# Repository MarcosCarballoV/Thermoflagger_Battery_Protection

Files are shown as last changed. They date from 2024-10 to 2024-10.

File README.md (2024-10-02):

# Thermoflagger Battery Protection Overheat




## Overview

This design monitors battery temperature to protect LiPo and Li-ion batteries from overheating. It disconnects the battery at 60°C and automatically reconnects at 50°C, ensuring safety during charging and discharging cycles while consuming just 2.6 µA in overheat protection mode.

The Toshiba Thermoflagger (model TCTH011AE) is essential for automatic battery disconnection and reconnection, as non-latch models are unsuitable for this purpose. Additionally, the design incorporates the BQ24075 battery charger IC, which features a dedicated pin for battery disconnection, further enhancing safety with real-time

<p align="center">
  Thermoflagger_Operating
  <br>
  <em>Thermoflagger - Automatic battery disconnection and reconnection </em>
</p>

## Thermoflagger

Toshiba’s Thermoflagger™ devices are designed for effective over-temperature monitoring and protection. These devices utilize a constant current source to detect temperature changes, ensuring high accuracy without the need for supply voltage stabilization.

### How the IC Operates
The Thermoflagger™ connects to a PTC thermistor via the PTCO pin. The built-in constant current source generates a low voltage across the PTC thermistor. As temperature increases, the resistance of the thermistor rises exponentially, causing a voltage increase at the PTCO pin. This voltage change is detected by the Thermoflagger™, which then generates a FLAG signal to the MCU for further actions. Multiple PTC thermistors can be connected in series for monitoring at various points within a system.

<p align="center">
  Thermoflagger_HowOperates
  <br>
  <em>How the Thermoflagger Operates</em>
</p>

### Features
- **High accuracy:** No supply voltage stabilization required.
- **Current source for temperature detection:** Efficient and reliable.

### Overheat Detection
The Thermoflagger™ provides a warning signal upon detecting a change in resistance in the PTC thermistor, indicating potential overheat conditions.

## BQ24075 Overview
The BQ24075 is part of the BQ2407x series of integrated Li-Ion linear chargers and system power path management devices, specifically designed for space-limited portable applications.

This device features **Battery Disconnect Function** with a SYSOFF input, ensuring that the battery can be disconnected safely when needed.

<p align="center">
  BQ24075_Circuit
  <br>
  <em>BQ24075 - Typical Application Circuit</em>
</p>

### Key Features
- **Dynamic Power Path Management (DPPM):** Allows the system to power while simultaneously and independently charging the battery.
- **Up to 1.5-A Charge Current:** Supports a maximum charge current of 1.5 A with a current monitoring output (ISET).
- **Programmable Input Current Limit:** Configurable up to 1.5 A for wall adapters, providing flexibility in charging options.
- **Safety Features:** Includes reverse current, short-circuit, and thermal protection for enhanced reliability.
- **NTC Thermistor Input:** Integrates with NTC thermistors for temperature monitoring, ensuring safe operation during charging cycles.

## Analysis for Adapting the Thermoflagger

### Replacing PTC with NTC
Most PTC thermistors I found have a reference resistance (double of R25) at 80°C or higher. We need a significant difference in resistivity between a normal operating temperature of 25°C and 60°C. Therefore, PTC thermistors are ruled out, leaving us with NTC thermistors as the viable option.

<p align="center">
  double of R25
  <br>
  <em>PTC - Rref(Double of R25)</em>
</p>

**In theory, it is possible to replace PTC thermistors with NTC thermistors**, as the Thermoflagger operates based on a current source and a comparator with a reference of 0.5 V.

<p align="center">
  NTC and PTC curves
  <br>
  <em>NTC and PTC curves</em>
</p>

Using a current of 1 µA, the total resistance required is 500 kΩ. We can also place a resistor in series with the NTC to adjust the activation threshold to the desired temperature, in our case, 60°C.

<p align="center">
  <table>
    <tr>
      <td align="center">
        <em>Normal state</em>
        <br>
        <br>
        Thermoflagger_WithNTC_25C
        <br>
        <em>Thermoflagger at 25°C</em>
      </td>
       <td align="center">
        <em>Over temperature state</em>
        <br>
         <br>
        Thermoflagger_WithNTC_60C
        <br>
        <em>Thermoflagger at 60°C</em>
      </td>
    </tr>
  </table>
</p>

## Optimizing the Design

To develop an efficient battery protection system that disconnects at 60°C and reconnects after cooling, we must answer the following key questions:
- Which NTC to choose: 470kΩ or 1MΩ?
- Does the beta coefficient of the NTC matter or influence the design significantly?
- What will be the battery disconnect and reconnect temperatures?

### Using the NTCG164QH105HT1
We will use the NTCG164QH105HT1 from TDK in the project, as it is available from Mouser and its datasheet provides reliable specifications:
- Resistance: 1MΩ at 25°C.
- Beta: 4450K.
- [Product link](https://www.mouser.com/ProductDetail/TDK/NTCG164QH105HT1?qs=YdQ7Kj7W0bx%2FBItKU4CZUQ%3D%3D).

## Simulation and Calculations

The first step was to create a project in Wolfram Mathematica to derive formulas and generate graphs. The initial graph plotted the resistance of the NTC against temperature.

<p align="center">
  NTCG164QH105HT1
  <br>
  <em>NTC Resistance vs Temperature</em>
</p>

Next, we needed a simulation of a constant current source of 1µA and the NTC. For this, a project in Proteus was sufficient. A resistor in series with the NTC was added to the circuit.

<p align="center">
  ProteusSimul
  <br>
  <em>Proteus Simulation</em>
</p>

With this setup, we could proceed with the calculations to determine the required value of the series resistor (R1) to ensure battery disconnection at 60°C. For this, the voltage drop across the resistor and the NTC needed to be 0.45V. This is because the non-latching version of the Thermoflagger has a hysteresis of 0.1V, meaning the thresholds are at ±0.05V from 0.5V.

```mathematica
(*Parameters*)

R25 = 1000000; (*Resistance at 25°C in ohms*)
beta := 4750; (*Beta coefficient*)

(*Function for the resistance at a temperature T in Kelvin*)
R[T_] := R25*Exp[beta*(1/T - 1/298.15)]

VoltageTH := 0.45;
Current := 1 10^-6

(*Calculate R1*)
R1 = VoltageTH/Current - Round[R[60 + 273.15]]
```
Next, we plotted the voltage across the NTC as a function of temperature. This helps us visualize the cutoff and transition regions of the Thermoflagger, considering the hysteresis.
The Thermoflagger has a hysteresis of 0.1V, with the switching points at ±0.05V from the 0.5V reference. The goal of the graph is to show how the voltage changes with temperature and identify the points where the logic state of the Thermoflagger transitions between high and low.

From this point forward, we will not show any additional code. The full Wolfram Mathematica project, including the formulas and plots, will be available in the repository.

<p align="center">
  GraphNTC_1M
  <br>
  <em>Window Hysterisis Thermoflagger - Voltage vs Temperature</em>
</p>

This configuration gives us a region:
- At 50°C, the NTC and the resistor have a voltage of 0.55V.
- At 60°C, the NTC and the resistor have a voltage of 0.45V.

We have a region of 10°C, this is the temperature difference required to switch between logic states.

### Which Beta is the Best?

Setting the threshold to 0.45V at 60°C:
- What is the best beta coefficient that minimizes the temperature difference (ΔTbeta)?
 
By calculating the difference between the two points where the voltage is 0.55V and 0.45V as Beta varies, we obtain the following graph:

<p align="center">
  Delta T vs Beta
  <br>
  <em>Delta TBeta vs Beta</em>
</p>

We see that to minimize the difference between the points (ΔTBeta), a beta coefficient of 3242K would give us a temperature range of 9.08°C. This is not a significant difference compared to our NTC with a beta of 4450K, which provides a range of 9.7°C.

Finally, we need to analyze whether all beta values are feasible, given that we have a series resistance (R1). By plotting the value of the resistance \( R1 \) such that at 60°C, the NTC and the resistor have a voltage of 0.45V as beta varies, we obtain the following graph:

<p align="center">
  Resistor R1 vs Beta
  <br>
  <em>Resistor R1 vs Beta</em>
</p>

For Resistance R1 to be positive, there must be a beta greater than 2200 K.

### And NTC with 470 kΩ?

We also need to analyze the same situation for an NTC with a resistance at ambient temperature (25°C) of 470 kΩ and a beta coefficient of 4450K.

<p align="center">
  <table>
    <tr>
      <td align="center">
        Delta T vs Beta 470K
        <br>
        <em>Delta TBeta vs Beta</em>
      </td>
       <td align="center">
        Resistor R1 vs Beta 470K
        <br>
        <em>Resistor R1 vs Beta</em>
      </td>
    </tr>
  </table>
</p>

We observe that with the same beta of 4450K, we obtain an increase in the window size (ΔTBeta), reaching 16.82°C. However, even with the best possible beta, ΔTBeta has a value of 16.5°C. 

This analysis leads us to conclude that the 1M NTC remains the best option for our design.

## Schematics

The schematic is based on the BQ24075 battery charger and the Thermoflagger. In this design, the PCB was intended to test different Thermoflagger models (with Latch, without Latch, Push-Pull, or OpenDrain). Therefore, the PCB includes SMD jumpers, pull-up resistors, a button, and a circuit to invert the digital signal from the Thermoflagger. However, during testing, only the non-Latch, Push-Pull model (TCTH011AE) was required, and there was no need to invert the signal.

To measure current consumption in the overheat protection state, a TH jumper was added to connect a power consumption meter, such as the PPK2 from Nordic. Additionally, LEDs are included as a load, and another indicates when the battery starts charging, alongside a USB connector to power the battery charging.

<p align="center">
  Schematic
  <br>
  <em>Schematic Design</em>
</p>

## 3D Model Design

<p align="center">
  Thermoflagger PCB Design Render
  <br>
  <em>Thermoflagger PCB Design Render</em>
</p>

## Current Discharge in Overheat

Using the PPK2, the battery current consumption was measured when the Thermoflagger sends a high logic signal to the SYSOFF pin, disconnecting the battery from the load circuit, which is seen at the BQ24075's output (in this design, a LED that consumes around 0.5 mA).

<p align="center">
  CurrentPPK2
  <br>
  <em>Current Discharge in Overheat with PPK2</em>
</p>

It was observed that the Thermoflagger is the only component consuming current in the overheat state, with an average consumption of approximately 2.2 µA.

## Disconnect Battery During Charging?

When the NTC reaches a high temperature, the BQ24075 disconnects the battery from the load. This disables the device from running on the battery, but it can still function via USB. This means that in an overheat state, the device can only operate with USB power; however, it will not charge the battery as it remains disconnected.

Once it cools down sufficiently, to around 50°C, the Thermoflagger sets the SYSOFF pin to LOW, reconnecting the battery to the system.

<p align="center">
  Battery Discconect
  <br>
  <em>Battery Disconnect</em>
</p>

It is shown that the battery charges via USB power with a current of around 600 mA, but when it reaches the overheat state, this drops to 0 mA. It is possible that the battery continues to charge with a current in the range of nanoamperes (nA) or a few microamperes (µA).

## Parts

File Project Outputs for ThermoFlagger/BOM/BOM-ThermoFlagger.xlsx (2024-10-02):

Comment | Description | Designator | Footprint | LibRef | Quantity | Manufacturer Part Number | Manufacturer | Stock 1 | Pricing 1 | Supplier Unit Price 1 | Supplier Stock 1 | Manufacturer 1 | Manufacturer Part Number 1
JST-SH 3-pin Right | Connector Header, SR Series, 3 Position, 1.00mm, 50V | BATT | JST_BM03B-SRSS-RightAngle | JST-SH 3-pin Right | 1 | BM03B-SRSS-TB(LF)(SN) | JST | 136525 | 5=0.1844, 50=0.1492, 150=0.1342, 1500=0.1078, 3000=0.0997, 4500=0.0948 (USD) |  | 35523 | JST | BM03B-SRSS-TB(LF)(SN)
4.7uF/16V | 0603 4.7 uF 16 V ±10% Tolerance X5R Multilayer Ceramic Capacitor | C1, C3 | C0603 | C0603 4.7uF/16V | 2 | GRT188R61C475KE13D | Murata | 39950 | 1=0.16, 10=0.066, 50=0.066, 100=0.038, 1000=0.034, 10000=0.029 (USD) | 0.25 | 62713 | Murata | GRT188R61C475KE13D
1uF/16V | MLCC 1uF 16V X5R 10% SMD 0603 85C Paper T/R | C2, C4 | C0603 | C0603 1uF/16V X5R | 2 | CC0603KRX5R7BB105 | Yageo | 726921 | 1=0.17000, 10=0.09100, 50=0.09100, 100=0.04100, 1000=0.03400, 10000=0.02100 (USD) | 0.1 | 13679 | Yageo | CC0603KRX5R7BB105
GREEN | Green 575nm LED Indication - Discrete 2V 0603 | D1 | LED 0603 | LED 0603 GREEN | 1 | 150060VS55040 | Wurth Electronics | 24940 | 1=0,18000, 10=0,16200, 50=0,16200, 100=0,14700, 1000=0,11700, 10000=0,11700 (USD) | 0.19 | 41565 | Wurth Electronics | 150060VS55040
RED | Red 625nm LED Indication - Discrete 2V 0603 | D2 | LED 0603 | LED 0603 RED | 1 | 150060RS55040 | Wurth Electronics | 8586 | 1=0.18000, 10=0.16200, 100=0.14700, 500=0.13200, 1000=0.11700, 2000=0.11700 (USD) | 0.19 | 20766 | Wurth Electronics | 150060RS55040
USB4135-GF-A_REVA | Usb C Rec Gf Ra 6P SMT & SMT She | J2 | GCT_USB4135 16-pin | USB4135-GF-A_REVA | 1 |  |  | 1196 | 1=0.67300, 50=0.59700, 100=0.56000, 250=0.52200, 500=0.46600, 1000=0.43300, 1500=0.40000, 3000=0.33600 (USD) | 0.76 | 7332 | Global Connector Technology | USB4135-GF-A
Header Male 1x02 Jumper | Header Male Jumper 1x02 | J4 | Header 1x02 Jumper | Header Male Jumper 1x02 | 1
0.19A/1.1V | MOSFET Transistor, N Channel, 190 mA, 60 V, 3 ohm, 10 V, 1.6 V | Q1 | SOT-23-3 | MOSFET N-CH NX7002AK,215 | 1 | NX7002AK,215 | Nexperia | 451760 | 1=0.18, 10=0.131, 50=0.131, 100=0.059, 1000=0.036, 10000=0.021 (USD) | 0.15 | 285216 | Nexperia | NX7002AK,215
1.2K | RES 0603 1.2K OHM 1% 1/10W | R1, R2, R3 | R0603 | R0603 1.2K | 3 | RC0603FR-071K2L | Yageo | 27884 | 1=0.10000, 10=0.02400, 50=0.02400, 100=0.01000, 1000=0.00400, 10000=0.00300 (USD) | 0.1 | 198155 | Yageo | RC0603FR-071K2L
1.5K | RES 0603 1.5K OHM 0.5% 1/10W | R4 | R0603 | R0603 1.5K | 1 | RC0603FR-071K5L | Yageo | 312486 | 1=0.10000, 10=0.01800, 50=0.01800, 100=0.00600, 1000=0.00500, 10000=0.00300 (USD) | 0.1 | 1021270 | Yageo | RC0603FR-071K5L
10K | SMD Chip Resistor, 10 kOhm, ± 1%, 100 mW, 0603 [1608 Metric], Thick Film, Anti-Sulfur | R5 | R0603 | R0603 10K | 1 |  |  |  |  | 0.1 | 61565 | Yageo | AF0603FR-0710KL
5.1K | RES 0603 5.1K OHM 1% 1/10W | R6, R7 | R0603 | R0603 5.1K | 2 | RC0603FR-075K1L | Yageo | 557916 |  | 0.1 | 160260 | Yageo | RC0603FR-075K1L
100K | RES 0603 100K OHM 1% 1/10W | R8, R9 | R0603 | R0603 100K | 2 |  |  | 4536807 | 1=0.10000, 10=0.02100, 100=0.00900, 1000=0.00400, 5000=0.00300, 10000=0.00200 (USD) | 0.1 | 233855 | Yageo | RC0603FR-07100KL
260K | RES 0603 215K OHM 1% 1/10W | R10 | R0603 | R0603 215K | 1 |  |  | 61268 | 1=0,10000, 10=0,01800, 50=0,01800, 100=0,00700, 1000=0,00400, 10000=0,00200 (USD) | 0.1 | 78119 | Yageo | RC0603FR-07215KL
1M | RES 0603 1M OHM 1% 1/10W | R11 | R0603 | R0603 1M | 1 |  |  | 1321822 | 1=0.10000, 10=0.01800, 50=0.01800, 100=0.00700, 1000=0.00400, 10000=0.00200 (USD) | 0.1 | 219218 | Yageo | RC0603FR-071ML
TL6340AF160Q 0.8mm | TACTILE SWITCH, SPST, 0.02A/12VDC, SMD; Product Range: TL6340 Series; Actuator Orientation: Side Actuated; Switch... | S1 | TL6340AF160Q | TL6340AF160Q 0.8mm | 1 | TL6340AF160Q | E-Switch | 2636 | 1=0.51, 10=0.478, 50=0.478, 100=0.46, 1000=0.36, 10000=0.255 (USD) | 0.51 | 4849 | E-Switch | TL6340AF160Q
BQ24075RGTR | IC LI-ION CHARGE MGMT 16-QFN | U1 | VQFN16 | BQ24075RGTR | 1 | BQ24075RGTR | Texas Instruments | 21933 | 1=2.52000, 10=2.27000, 50=2.14000, 100=1.82000, 1000=1.24000, 10000=1.24000 (USD) | 2.35 | 11179 | Texas Instruments | BQ24075RGTR
TCTH012AE | Supervisory Circuits CMOS Linear IC Over Temp Detection IC IPTCO: 1uA Latching-func PTCGOOD: Push-Pull | U2 | SOT-553 (ESV) | TCTH012AE | 1 |  |  | 8000 | 1=0.38, 10=0.296, 50=0.296, 100=0.265, 1000=0.201, 10000=0.154 (USD) | 0.38 | 8000 | Toshiba | TCTH012AE,LF(CT

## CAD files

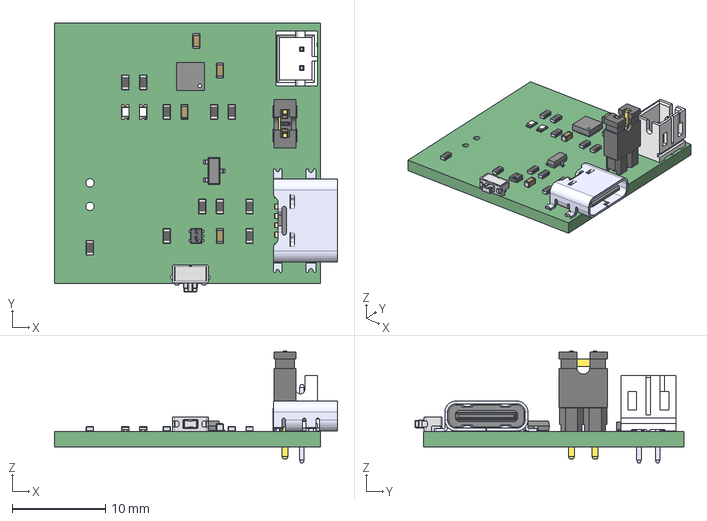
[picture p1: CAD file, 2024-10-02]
Project Outputs for ThermoFlagger/STEP/ThermoFlagger.step
30.4 x 28.9 x 12.0 mm

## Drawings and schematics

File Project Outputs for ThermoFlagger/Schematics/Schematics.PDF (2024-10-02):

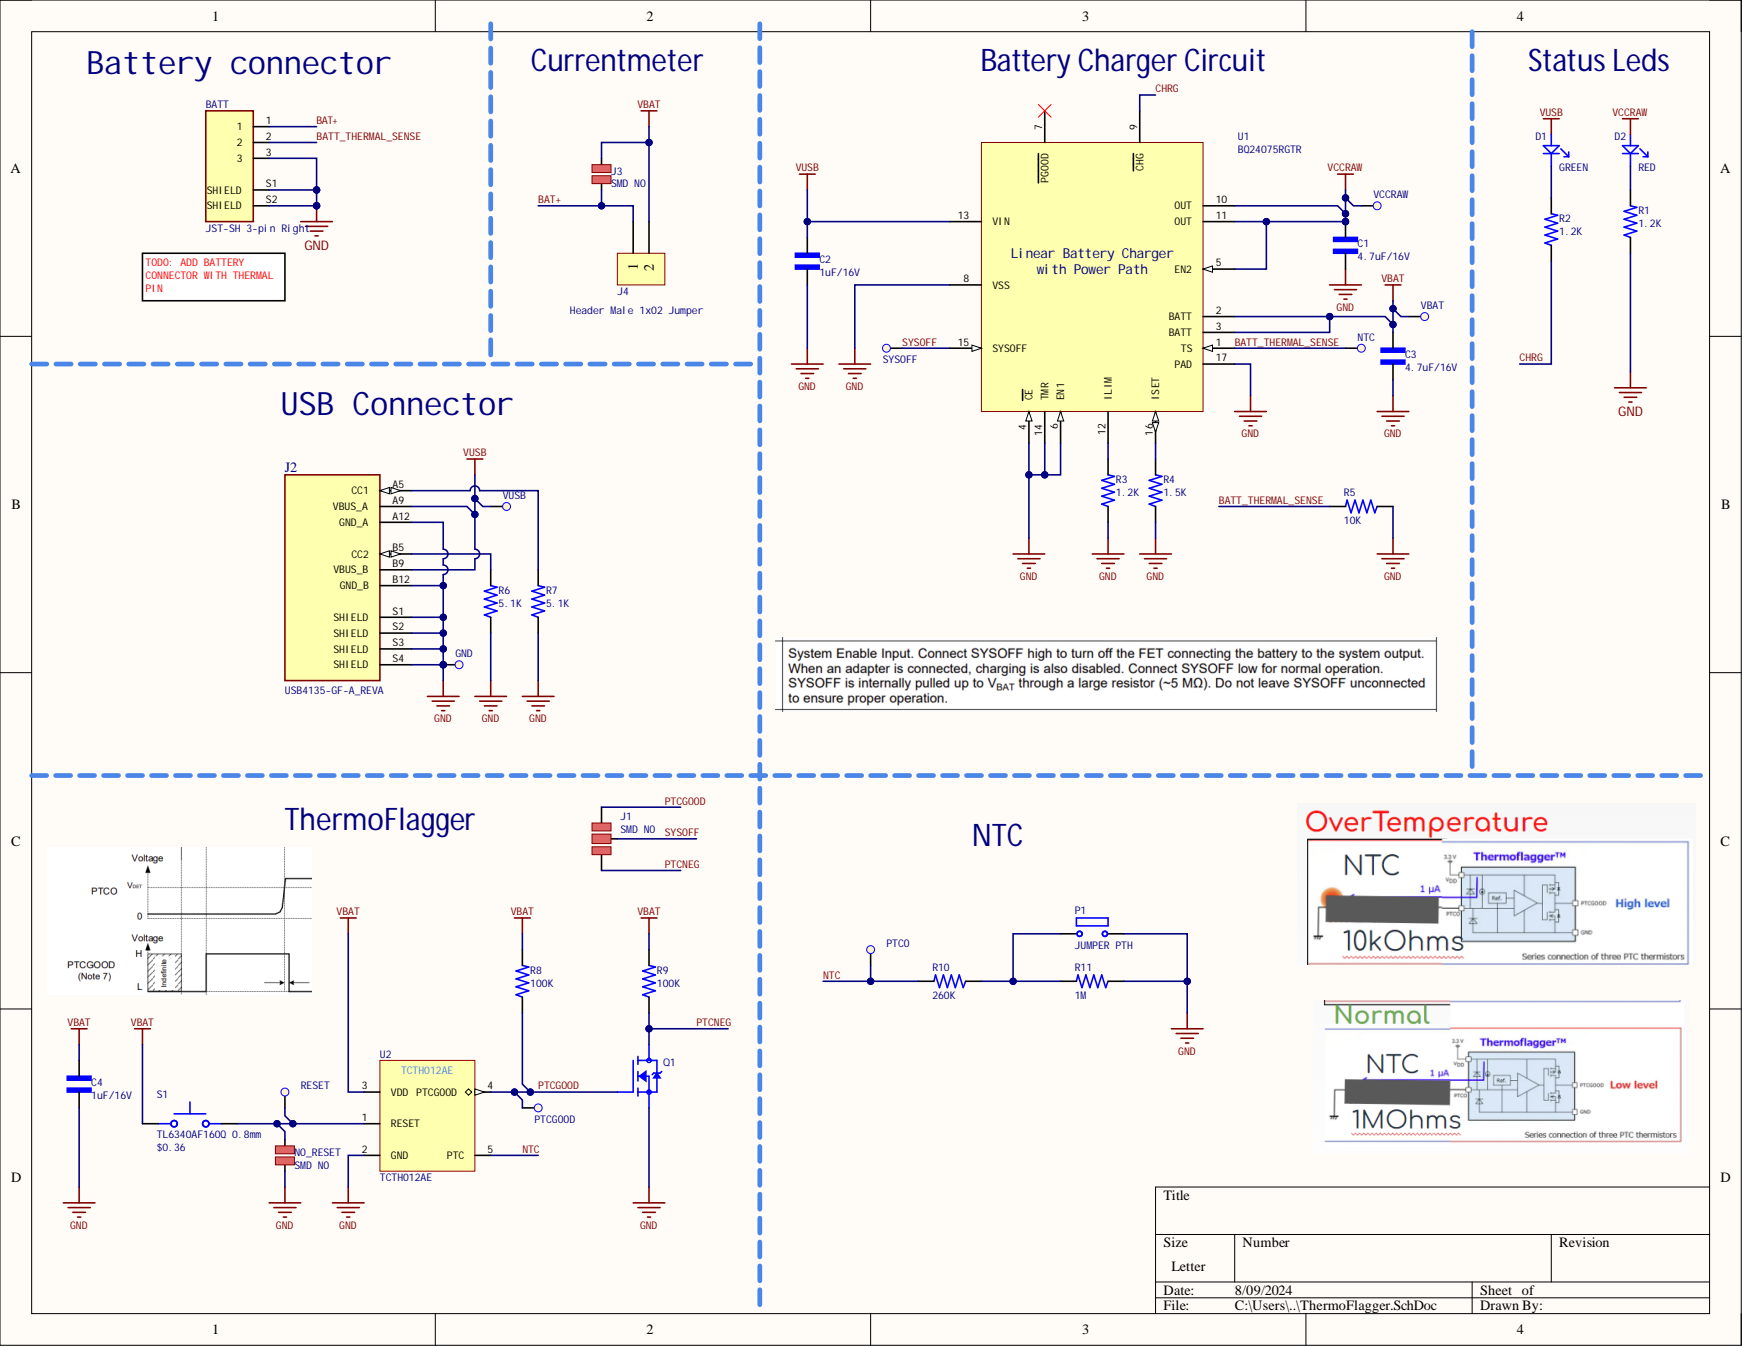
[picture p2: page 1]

JST-SH 3-pin Right

VSS 8

SYSOFF | SYSOFF 15
